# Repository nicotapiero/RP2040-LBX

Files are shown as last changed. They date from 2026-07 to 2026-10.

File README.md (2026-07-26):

# RP2040 LBX Compatible PCB

Initially forked from the [4.0 Version of the GRAM-SLIM](https://github.com/GRAMCTRL/GRAM-SLIM)

Thanks @beyondperfectly in the JFA Discord for the intial measurements: https://discord.com/channels/659775676542353438/888150700322861076/1038660816783802388

### Required Footprint Libraries:

* https://github.com/quark-works/qw-footprints/ (added as Git Submodule)
* [SW_choc_v1_HS_1u](https://github.com/ebastler/marbastlib/blob/6b0a9a73f579e377816d60b58eac2b3252de7868/footprints/marbastlib-choc.pretty/SW_choc_v1_HS_CPG135001S30_1u.kicad_mod)
* [SOIC-8_5.23x5.23mm_P1.27mm](https://github.com/KiCad/kicad-footprints/blob/master/Package_SO.pretty/SOIC-8_5.23x5.23mm_P1.27mm.kicad_mod)
* [CON_TC2030_outlined](https://github.com/ebastler/marbastlib/blob/6b0a9a73f579e377816d60b58eac2b3252de7868/footprints/marbastlib-various.pretty/CON_TC2030_outlined.kicad_mod)
* [ul_TS-1187A-B-A-B](https://app.ultralibrarian.com/details/34b5192a-fcd3-11ec-b159-0a34d6323d74/XKB-Connectivity/TS-1187A-B-A-B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)

`.gitignore` for KiCad from [official Github repo](https://github.com/github/gitignore/blob/5b24c9042da72fcdcbe77dd5043243c987151d64/KiCad.gitignore)

Button layout to-scale diagram provided by LBX in their manual: https://docs.google.com/document/d/1tbTJEMjoW81OzD7IcGiDwz86cqZ35NQjBmwLq3tH4vI/edit?tab=t.0

Buttons confirmed rotated 9 degrees: https://discord.com/channels/659775676542353438/888150700322861076/1085662648756097205

PS Buttons confirmed TS-1187A-C-G-A or TS-1187A-C-G-B: https://discord.com/channels/659775676542353438/888150700322861076/1376599778439463015

## Disclaimer

This is an independent, community-developed replacement PCB compatible with the JFA LBX controller.

This project is not affiliated with, endorsed by, or sponsored by JFA. "JFA" and "LBX" are used solely to describe compatibility.

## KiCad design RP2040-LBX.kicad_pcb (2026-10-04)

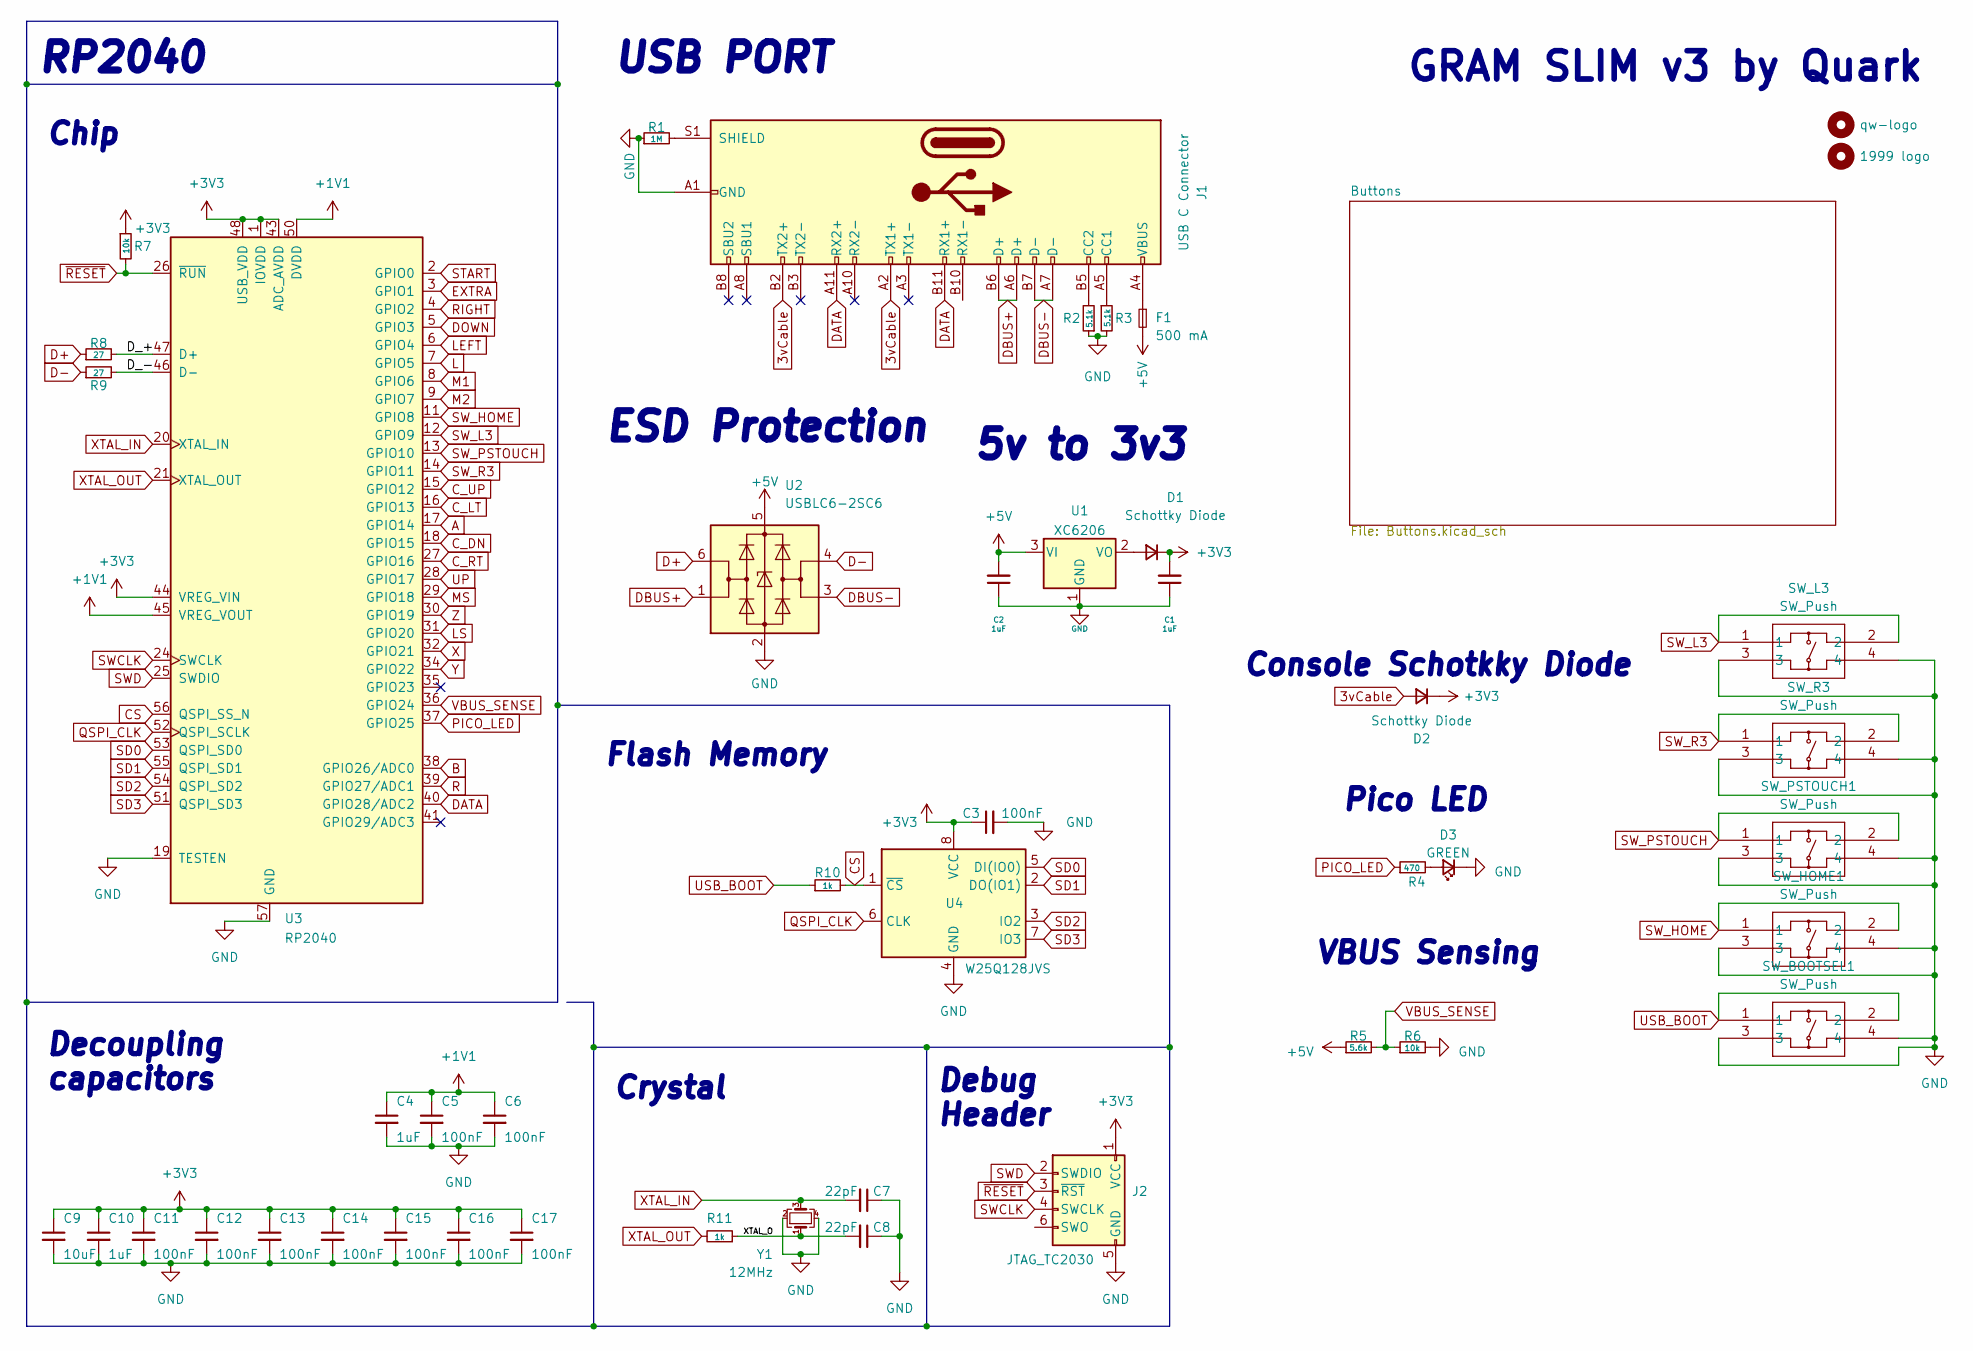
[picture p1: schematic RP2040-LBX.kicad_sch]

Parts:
C1, C2, C4, C10: 1uF; C_0402_1005Metric; LCSC C52923
C3, C5, C6, C11, C12, C13, C14, C15, C16, C17: 100nF; C_0402_1005Metric; LCSC C1525
C7, C8: 22pF; C_0402_1005Metric; LCSC C1555
C9: 10uF; C_0402_1005Metric; LCSC C15525
D1, D2: Schottky Diode; D_SOD-123; LCSC C130880
D3: GREEN; LED_0805_2012Metric; LCSC C2297
F1: 500 mA; Fuse_1206_3216Metric; LCSC C2836286
H1: qw-logo; qw new logo silk + copper md
H2: 1999 logo; 1999 logo md
J1: USB C Connector; TYPE-C_24P_QCHT; LCSC C456013
J2: JTAG_TC2030; CON_TC2030_outlined
R1: 1M; R_0603_1608Metric; LCSC C22935
R2, R3: 5.1k; R_0402_1005Metric; LCSC C25905
R4: 470; R_0402_1005Metric; LCSC C25117
R5: 5.6k; R_0603_1608Metric; LCSC C23189
R6: 10k; R_0603_1608Metric; LCSC C25804
R7: 10k; R_0402_1005Metric; LCSC C25744
R8, R9: 27; R_0603_1608Metric; LCSC C25190
R10, R11: 1k; R_0402_1005Metric; LCSC C11702
SW_BOOTSEL1: SW_Push; TS-1187A-B-A-B_XKB; LCSC C318886
SW_HOME1: SW_Push; TS-1187A-B-A-B_XKB; LCSC C318886
SW_L3: SW_Push; TS-1187A-B-A-B_XKB; LCSC C318886
SW_PSTOUCH1: SW_Push; TS-1187A-B-A-B_XKB; LCSC C318886
SW_R3: SW_Push; TS-1187A-B-A-B_XKB; LCSC C318886
U1: XC6206; SOT-23; LCSC C5446
U2: USBLC6-2SC6; SOT-23-6; LCSC C2827654
U3: RP2040; RP2040-QFN-56; LCSC C2040
U4: W25Q128JVS; SOIC-8_5.23x5.23mm_P1.27mm; LCSC C97521
Y1: 12MHz; Crystal_SMD_3225-4Pin_3.2x2.5mm; LCSC C9002

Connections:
3vCable: D2.2 (A), J1.A2 (TX1+), J1.B2 (TX2+)
+1V1: C4.1, C5.1, C6.1, U3.23 (DVDD), U3.45 (VREG_VOUT), U3.50 (DVDD)
+3V3: C1.2, C3.1, C9.1, C10.1, C11.1, C12.1, C13.1, C14.1, C15.1, C16.1, C17.1, D1.1 (K), D2.1 (K), J2.1 (VCC), R7.1, U3.1 (IOVDD), U3.10 (IOVDD), U3.22 (IOVDD), U3.33 (IOVDD), U3.42 (IOVDD), U3.43 (ADC_AVDD), U3.44 (VREG_VIN), U3.48 (USB_VDD), U3.49 (IOVDD), U4.8 (VCC)
+5V: C2.2, F1.2, R5.1, U1.3 (VI), U2.5 (VBUS)
/D_+: R8.2, U3.47 (D+)
/D_-: R9.2, U3.46 (D-)
/XTAL_O: C8.2, R11.1, Y1.1
A: U3.17 (GPIO14); also elsewhere on the board
B: U3.38 (GPIO26/ADC0); also elsewhere on the board
CS: R10.2, U3.56 (QSPI_SS_N), U4.1 (~CS)
C_DN: U3.18 (GPIO15); also elsewhere on the board
C_LT: U3.16 (GPIO13); also elsewhere on the board
C_RT: U3.27 (GPIO16); also elsewhere on the board
C_UP: U3.15 (GPIO12); also elsewhere on the board
D+: R8.1, U2.6 (I/O1)
D-: R9.1, U2.4 (I/O2)
DATA: J1.A11 (RX2+), J1.B11 (RX1+), U3.40 (GPIO28/ADC2)
DBUS+: J1.A6 (D+), J1.B6 (D+), U2.1 (I/O1)
DBUS-: J1.A7 (D-), J1.B7 (D-), U2.3 (I/O2)
DOWN: U3.5 (GPIO3); also elsewhere on the board
EXTRA: U3.3 (GPIO1); also elsewhere on the board
GND: C1.1, C2.1, C3.2, C4.2, C5.2, C6.2, C7.1, C8.1, C9.2, C10.2, C11.2, C12.2, C13.2, C14.2, C15.2, C16.2, C17.2, D3.1 (K), J1.A1 (GND), J1.A12 (GND), J1.B1 (GND), J1.B12 (GND), J2.5 (GND), R1.1, R2.1, R3.2, R6.2, SW_BOOTSEL1.3, SW_BOOTSEL1.4, SW_HOME1.3, SW_HOME1.4, SW_L3.3, SW_L3.4, SW_PSTOUCH1.3, SW_PSTOUCH1.4, SW_R3.3, SW_R3.4, U1.1 (GND), U2.2 (GND), U3.19 (TESTEN), U3.57 (GND), U4.4 (GND), Y1.2, Y1.4; also elsewhere on the board
L: U3.7 (GPIO5); also elsewhere on the board
LEFT: U3.6 (GPIO4); also elsewhere on the board
LS: U3.31 (GPIO20); also elsewhere on the board
M1: U3.8 (GPIO6); also elsewhere on the board
M2: U3.9 (GPIO7); also elsewhere on the board
MS: U3.29 (GPIO18); also elsewhere on the board
unnamed: D1.2 (A), U1.2 (VO)
unnamed: D3.2 (A), R4.2
unnamed: F1.1, J1.A4 (VBUS), J1.A9 (VBUS), J1.B4 (VBUS), J1.B9 (VBUS)
unnamed: J1.A5 (CC1), R3.1
unnamed: J1.B5 (CC2), R2.2
unnamed: J1.S1 (SHIELD), R1.2
PICO_LED: R4.1, U3.37 (GPIO25)
QSPI_CLK: U3.52 (QSPI_SCLK), U4.6 (CLK)
R: U3.39 (GPIO27/ADC1); also elsewhere on the board
RIGHT: U3.4 (GPIO2); also elsewhere on the board
SD0: U3.53 (QSPI_SD0), U4.5 (DI(IO0))
SD1: U3.55 (QSPI_SD1), U4.2 (DO(IO1))
SD2: U3.54 (QSPI_SD2), U4.3 (IO2)
SD3: U3.51 (QSPI_SD3), U4.7 (IO3)
START: U3.2 (GPIO0); also elsewhere on the board
SWCLK: J2.4 (SWCLK), U3.24 (SWCLK)
SWD: J2.2 (SWDIO), U3.25 (SWDIO)
SW_HOME: SW_HOME1.1, SW_HOME1.2, U3.11 (GPIO8)
SW_L3: SW_L3.1, SW_L3.2, U3.12 (GPIO9)
SW_PSTOUCH: SW_PSTOUCH1.1, SW_PSTOUCH1.2, U3.13 (GPIO10)
SW_R3: SW_R3.1, SW_R3.2, U3.14 (GPIO11)
UP: U3.28 (GPIO17); also elsewhere on the board
USB_BOOT: R10.1, SW_BOOTSEL1.1, SW_BOOTSEL1.2
VBUS_SENSE: R5.2, R6.1, U3.36 (GPIO24)
X: U3.32 (GPIO21); also elsewhere on the board
XTAL_IN: C7.2, U3.20 (XTAL_IN), Y1.3
XTAL_OUT: R11.2, U3.21 (XTAL_OUT)
Y: U3.34 (GPIO22); also elsewhere on the board
Z: U3.30 (GPIO19); also elsewhere on the board
~RESET: J2.3 (~RST), R7.2, U3.26 (~RUN)

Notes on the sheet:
GRAM SLIM v3 by Quark
Flash Memory
5v to 3v3
Pico LED
Crystal
Chip
Console Schotkky Diode
RP2040
VBUS Sensing
Debug Header
USB PORT
ESD Protection
Decoupling capacitors

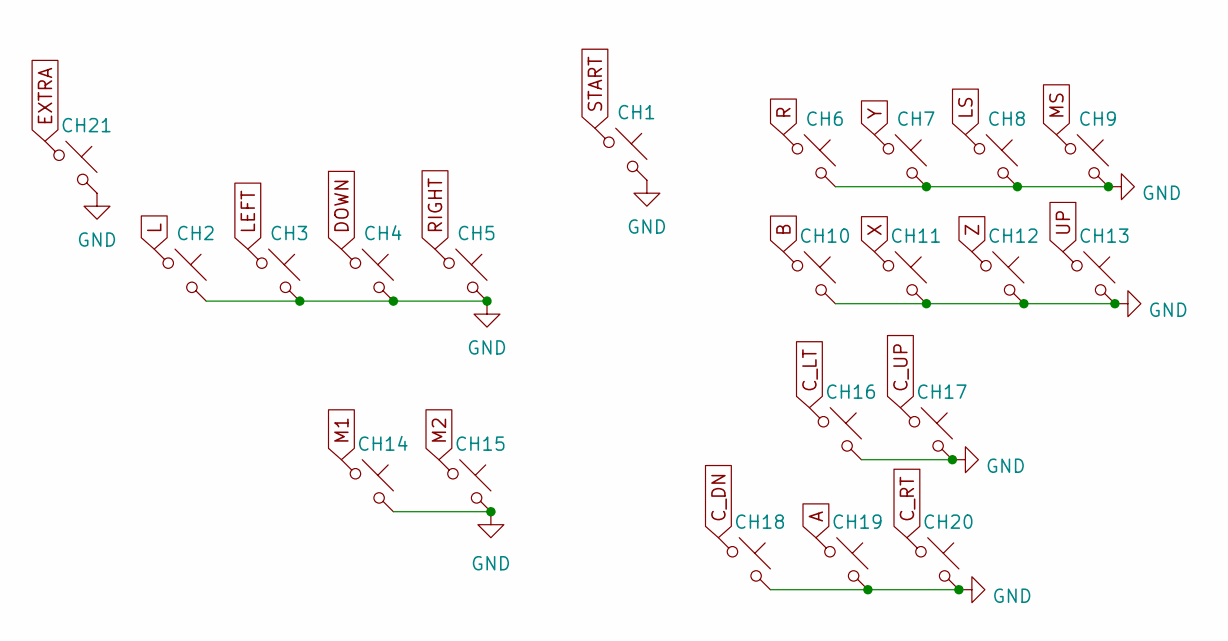
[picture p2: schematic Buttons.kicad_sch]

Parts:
CH1, CH2, CH3, CH4, CH5, CH6, CH7, CH8, CH9, CH10, CH11, CH12, CH13, CH14, CH15, CH16, CH17, CH18, CH19, CH20, CH21: choc_SW_HS; SW_choc_v1_HS_1u

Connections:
A: CH19.1; also elsewhere on the board
B: CH10.1; also elsewhere on the board
C_DN: CH18.1; also elsewhere on the board
C_LT: CH16.1; also elsewhere on the board
C_RT: CH20.1; also elsewhere on the board
C_UP: CH17.1; also elsewhere on the board
DOWN: CH4.1; also elsewhere on the board
EXTRA: CH21.1; also elsewhere on the board
GND: CH1.2, CH2.2, CH3.2, CH4.2, CH5.2, CH6.2, CH7.2, CH8.2, CH9.2, CH10.2, CH11.2, CH12.2, CH13.2, CH14.2, CH15.2, CH16.2, CH17.2, CH18.2, CH19.2, CH20.2, CH21.2; also elsewhere on the board
L: CH2.1; also elsewhere on the board
LEFT: CH3.1; also elsewhere on the board
LS: CH8.1; also elsewhere on the board
M1: CH14.1; also elsewhere on the board
M2: CH15.1; also elsewhere on the board
MS: CH9.1; also elsewhere on the board
R: CH6.1; also elsewhere on the board
RIGHT: CH5.1; also elsewhere on the board
START: CH1.1; also elsewhere on the board
UP: CH13.1; also elsewhere on the board
X: CH11.1; also elsewhere on the board
Y: CH7.1; also elsewhere on the board
Z: CH12.1; also elsewhere on the board

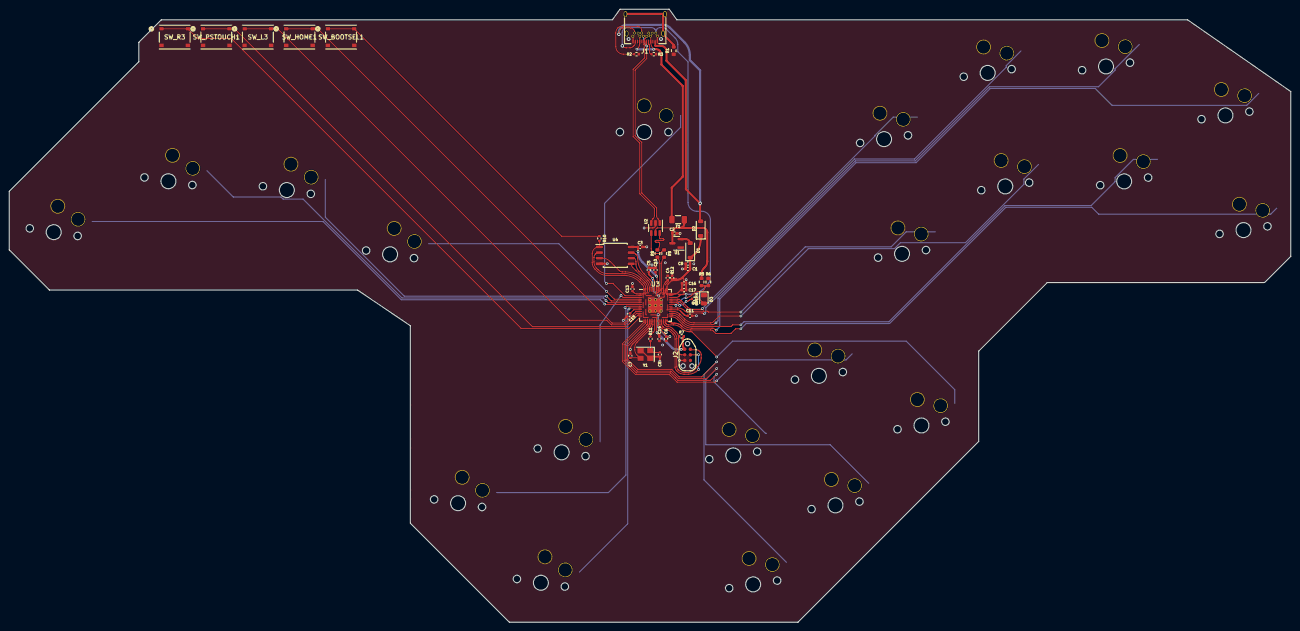
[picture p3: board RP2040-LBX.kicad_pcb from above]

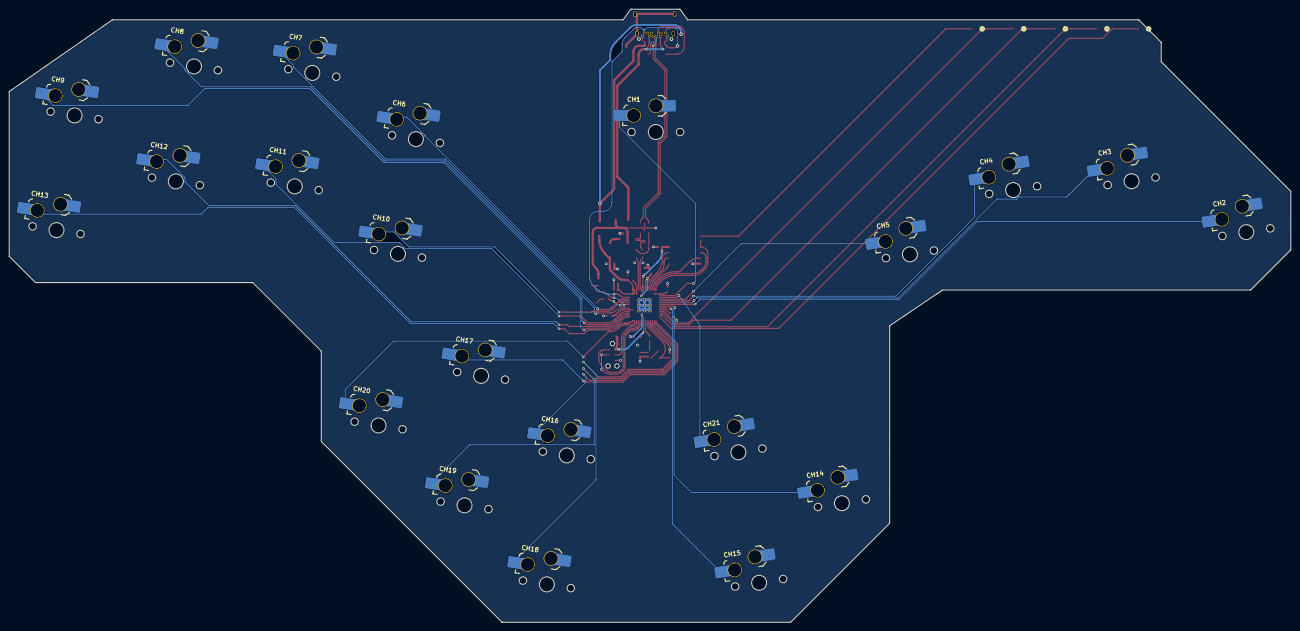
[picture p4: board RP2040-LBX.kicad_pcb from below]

Board: 2 copper layers, 290.7 x 139.1 mm, 65 parts (21 on the bottom side), 58 nets.

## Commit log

2026-07-05 Renamed Gram Slim files, added README
    [Buttons.kicad_sch, RP2040-LBX.kicad_pcb, RP2040-LBX.kicad_sch]
2026-07-12 Added official GitHub Kicad .gitignore
2026-07-12 update base files to new kicad version
    [RP2040-LBX.kicad_pcb]
2026-07-13 feat: find the button coordinates from pixelated image
2026-07-26 feat: add tactile switches to lbx
    [Buttons.kicad_sch, RP2040-LBX.kicad_sch]
2026-07-26 Add home button footprint library
2026-07-26 assign footprints to the push buttons
    [RP2040-LBX.kicad_sch]
2026-07-26 move switch connects to correct relative placement
    [RP2040-LBX.kicad_pcb]
2026-07-26 add part numbers
    [RP2040-LBX.kicad_sch]
2026-07-26 Add missing LCSC values to board
    [RP2040-LBX.kicad_sch]
2026-07-26 Update R1/R2/R3 LCSC values using IntegratedOF1 as source of truth
    [RP2040-LBX.kicad_sch]
2026-07-26 rescale switch connectors to proper proportion
    [RP2040-LBX.kicad_pcb]
2026-07-26 remove RP2040-LBX.kicad_prl
2026-07-26 update from schematic and put edge cuts in place
    [RP2040-LBX.kicad_pcb]
2026-07-26 move the placement of hotswap sockets slightly into position (eyeballed)
    [RP2040-LBX.kicad_pcb]
2026-09-07 place mcu components and route buttons
    [RP2040-LBX.kicad_pcb]
2026-09-07 place and route extra switches
    [RP2040-LBX.kicad_pcb, RP2040-LBX.kicad_sch]
2026-09-07 push the led closer to the middle
    [RP2040-LBX.kicad_pcb]
2026-09-07 add lcsc for switches
    [RP2040-LBX.kicad_pcb]
2026-10-04 fix: some routing; moved tactiles a bit
    [RP2040-LBX.kicad_pcb]
2026-10-04 fix: edge cuts smaller to fit any case
    [RP2040-LBX.kicad_pcb]
2026-10-04 fix: fill zones
    [RP2040-LBX.kicad_pcb]
